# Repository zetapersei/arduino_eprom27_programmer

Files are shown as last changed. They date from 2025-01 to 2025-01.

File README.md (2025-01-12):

# Programmer for EPROM 27 series (16-512) based on Arduino

*You can download the stable version on the "Releases" tab. It guarantees a working version of the source code, compiled by the GUI for Windows and a sketch for arduino.*

Compatible Chips List (not all chips are tested):

 * 27C16 (connects from 3 to 26 leg DIP28 socket)
 * 27C32 (connects from 3 to 26 leg DIP28 socket)
 * 27C64
 * 27C128
 * 27C256
 * 27C512

Before write, check programming voltage in datasheet! 

# Schematic

Based on the project: https://github.com/bouletmarc/BMBurner

Schematic

PCB divorced using autotracer. Not yet tested, but the prototype is working properly.

*Resistors R1 and R2 are indicated in the Arduino firmware. By default, the values are 10 kOhm and 1.5 kOhm.*

# Software

Software for PC written by Qt5.

Functions:

 * Read chip
 * Write chip
 * Verify and check for write (no bits to be set to 1)
 * Programming voltage control (for AVR in TQFP case)

GUI on Windows 10

Requared Windows 7 or later.

GUI on Ubuntu Mate

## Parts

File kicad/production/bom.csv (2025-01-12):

Designator | Footprint | Quantity | Value | LCSC Part #
D1, D2, D3, D4, D5 | D_DO-35_SOD27_P7.62mm_Horizontal | 5 | 1N4148
IC1 | DIP-16_W7.62mm_LongPads | 1 | 74HC595D
IC2 | DIP-16_W7.62mm_LongPads | 1 | 74595D
J2 | PinHeader_1x02_P2.54mm_Vertical | 1 | Conn_01x02
Q1, Q2, Q3, Q4, Q5 | TO-92_Inline | 5 | BC557
Q6, Q7, Q8 | TO-92_Inline | 3 | BC547
R1, R2 | R_Axial_DIN0207_L6.3mm_D2.5mm_P10.16mm_Horizontal | 2 | R
R10, R11, R3, R4, R5, R6, R7, R8, R9 | R_Axial_DIN0207_L6.3mm_D2.5mm_P10.16mm_Horizontal | 9 | 22K
R12, R13, R14, R15 | R_Axial_DIN0207_L6.3mm_D2.5mm_P10.16mm_Horizontal | 4 | 4.7K
R16, R17 | R_Axial_DIN0207_L6.3mm_D2.5mm_P10.16mm_Horizontal | 2 | 300
U1 | Arduino_Nano_Socket | 1 | NANO
U2 | MT3608 | 1 | DC-DC-STEP-UP-MT3608
U3 | DIP_Socket-28_W11.9_W12.7_W15.24_W17.78_W18.5_3M_228-1277-00-0602J | 1 | 27C512

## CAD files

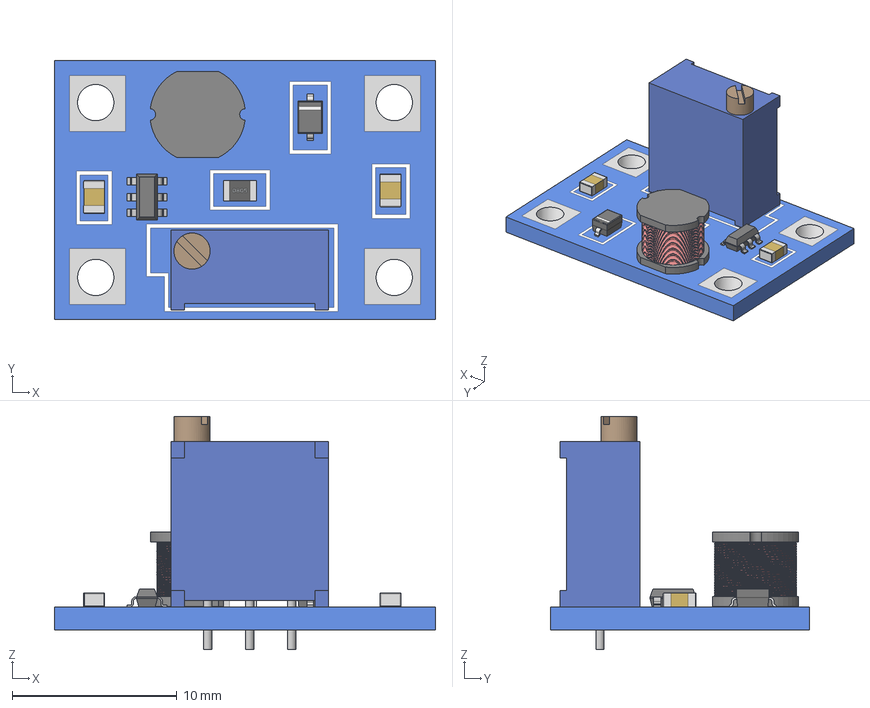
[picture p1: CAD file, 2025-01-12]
kicad/3D/Voltage Boost -Compact.stp
23.1 x 15.7 x 14.2 mm
MT3608-Module - Compact
Trimpot_3296W
0805 Capacitor x 2
CD54
sot-23-6-2
0805 Resistor
Diode (SOD-323)

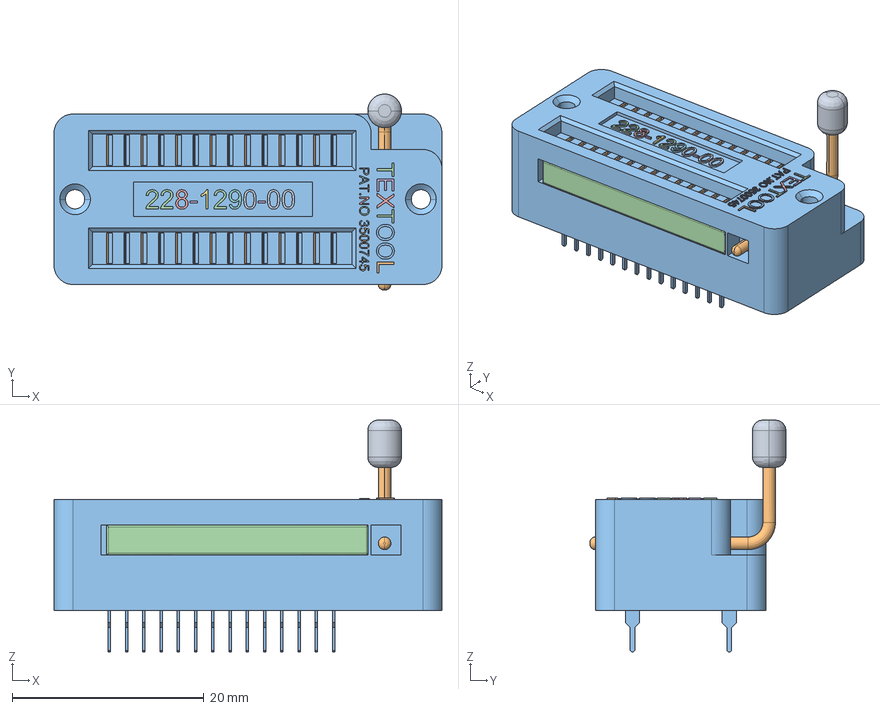
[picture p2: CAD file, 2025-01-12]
kicad/3D/textool.stp
40.5 x 20.5 x 24.2 mm

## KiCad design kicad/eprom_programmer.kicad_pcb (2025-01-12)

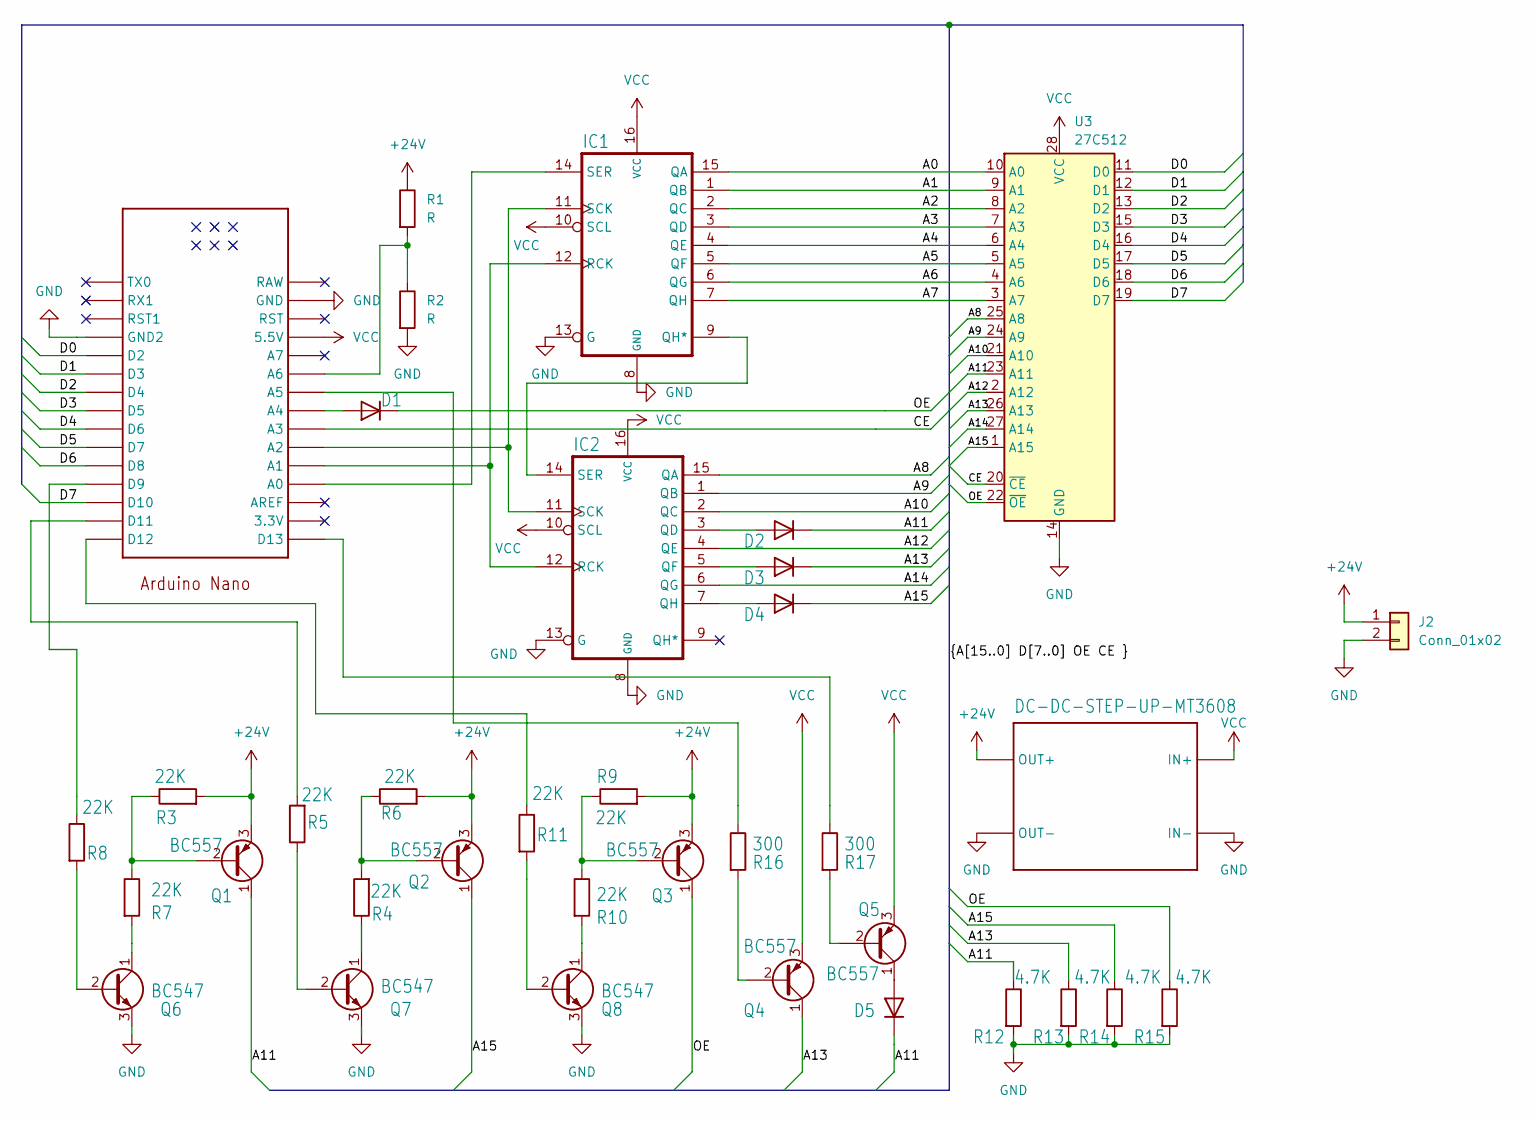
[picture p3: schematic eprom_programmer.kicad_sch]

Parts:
D1, D2, D3, D4, D5: 1N4148; D_DO-35_SOD27_P7.62mm_Horizontal
IC1: 74HC595D; DIP-16_W7.62mm_LongPads
IC2: 74595D; DIP-16_W7.62mm_LongPads
J2: Conn_01x02; PinHeader_1x02_P2.54mm_Vertical
Q1, Q2, Q3, Q4, Q5: BC557; TO-92_Inline
Q6, Q7, Q8: BC547; TO-92_Inline
R1, R2: R; R_Axial_DIN0207_L6.3mm_D2.5mm_P10.16mm_Horizontal
R3, R4, R5, R6, R7, R8, R9, R10, R11: 22K; R_Axial_DIN0207_L6.3mm_D2.5mm_P10.16mm_Horizontal
R12, R13, R14, R15: 4.7K; R_Axial_DIN0207_L6.3mm_D2.5mm_P10.16mm_Horizontal
R16, R17: 300; R_Axial_DIN0207_L6.3mm_D2.5mm_P10.16mm_Horizontal
U1: NANO
U2: DC-DC-STEP-UP-MT3608; MT3608
U3: 27C512; DIP_Socket-28_W11.9_W12.7_W15.24_W17.78_W18.5_3M_228-1277-0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

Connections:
+24V: J2.1, Q1.3 (E), Q2.3 (E), Q3.3 (E), R1.1, R3.2, R6.2, R9.2, U2.OUT+
/A0: IC1.15 (QA), U3.10 (A0)
/A1: IC1.1 (QB), U3.9 (A1)
/A2: IC1.2 (QC), U3.8 (A2)
/A3: IC1.3 (QD), U3.7 (A3)
/A4: IC1.4 (QE), U3.6 (A4)
/A5: IC1.5 (QF), U3.5 (A5)
/A6: IC1.6 (QG), U3.4 (A6)
/A7: IC1.7 (QH), U3.3 (A7)
/A8: IC2.15 (QA), U3.25 (A8)
/A9: IC2.1 (QB), U3.24 (A9)
/A10: IC2.2 (QC), U3.21 (A10)
/A11: D2.1 (K), D5.1 (K), Q1.1 (C), R12.1, U3.23 (A11)
/A12: IC2.4 (QE), U3.2 (A12)
/A13: D3.1 (K), Q4.1 (C), R13.1, U3.26 (A13)
/A14: IC2.6 (QG), U3.27 (A14)
/A15: D4.1 (K), Q2.1 (C), R14.1, U3.1 (A15)
/CE: U1.A3, U3.20 (~CE)
/D0: U1.D2, U3.11 (D0)
/D1: U1.D3, U3.12 (D1)
/D2: U1.D4, U3.13 (D2)
/D3: U1.D5, U3.15 (D3)
/D4: U1.D6, U3.16 (D4)
/D5: U1.D7, U3.17 (D5)
/D6: U1.D8, U3.18 (D6)
/D7: U1.D10, U3.19 (D7)
/OE: D1.1 (K), Q3.1 (C), R15.1, U3.22 (~OE)
GND: IC1.8 (GND), IC1.13 (G), IC2.8 (GND), IC2.13 (G), J2.2, Q6.3 (E), Q7.3 (E), Q8.3 (E), R2.2, R12.2, R13.2, R14.2, R15.2, U1.GND, U1.GND1 (GND2), U2.IN-, U2.OUT-, U3.14 (GND)
unnamed: D1.2 (A), U1.A4
unnamed: D2.2 (A), IC2.3 (QD)
unnamed: D3.2 (A), IC2.5 (QF)
unnamed: D4.2 (A), IC2.7 (QH)
unnamed: D5.2 (A), Q5.1 (C)
unnamed: IC1.9 (QH*), IC2.14 (SER)
unnamed: IC1.12 (RCK), IC2.12 (RCK), U1.A1
unnamed: IC1.11 (SCK), IC2.11 (SCK), U1.A2
unnamed: IC1.14 (SER), U1.A0
unnamed: Q1.2 (B), R3.1, R7.1
unnamed: Q2.2 (B), R4.2, R6.1
unnamed: Q3.2 (B), R9.1, R10.1
unnamed: Q4.2 (B), R16.2
unnamed: Q5.2 (B), R17.2
unnamed: Q6.2 (B), R8.2
unnamed: Q6.1 (C), R7.2
unnamed: Q7.2 (B), R5.1
unnamed: Q7.1 (C), R4.1
unnamed: Q8.2 (B), R11.2
unnamed: Q8.1 (C), R10.2
unnamed: R1.2, R2.1, U1.A6
unnamed: R5.2, U1.D11
unnamed: R8.1, U1.D9
unnamed: R11.1, U1.D12
unnamed: R16.1, U1.A5
unnamed: R17.1, U1.D13
VCC: IC1.10 (SCL), IC1.16 (VCC), IC2.10 (SCL), IC2.16 (VCC), Q4.3 (E), Q5.3 (E), U1.5V (5.5V), U2.IN+, U3.28 (VCC)

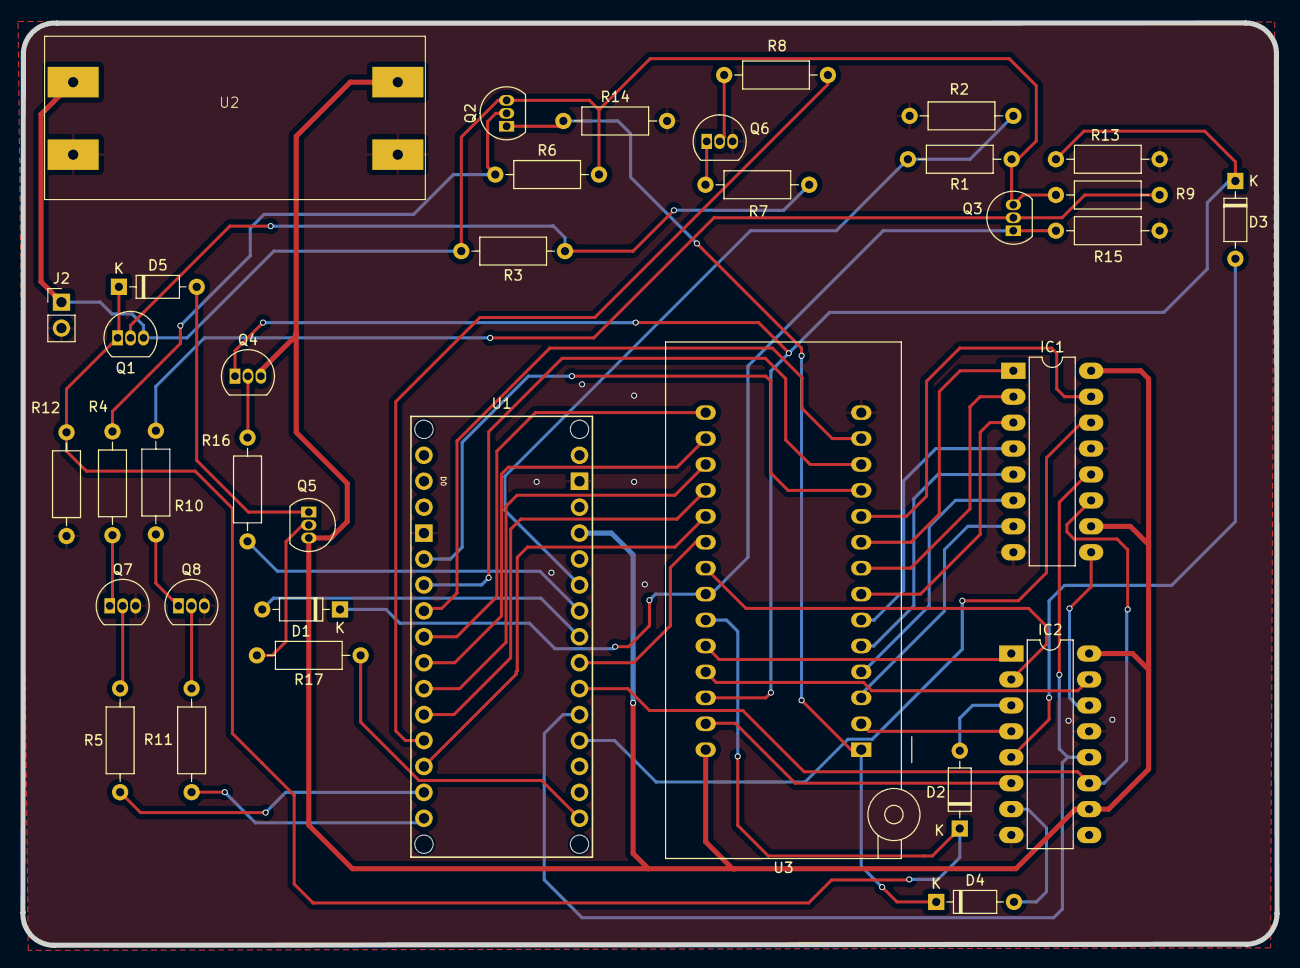
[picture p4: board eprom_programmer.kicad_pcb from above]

Board: 2 copper layers, 122.8 x 90.3 mm, 36 parts (0 on the bottom side), 55 nets.

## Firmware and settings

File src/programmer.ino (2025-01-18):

#include <Arduino.h>

#define TRUE 1
#define FALSE 0

/* 74HC595 control (address lines) */
#define shiftLatchPin A1
#define shiftClockPin A2
#define shiftDataPin A0
#define addressPinA10 13

/* Data pins */
#define dataB0 2
#define dataB1 3
#define dataB2 4
#define dataB3 5
#define dataB4 6
#define dataB5 7
#define dataB6 8
#define dataB7 10

/* Chip control */
#define chipEnable A3
#define outputEnable A4
#define powerEnable A5 // For 27C16 and 27C32
#define readVoltageEnable 13 // For 27C16
#define programVoltageEnableC16 9 // For 27C16
#define programVoltageEnableC32 12 // For 27C32 and 27C512
#define programVoltageEnableOther 11 // For other

/* Voltage control (for programming chips) */
#define voltageControl A6
#define rTop 10000.0
#define rBottom 1500.0

//#define MESSAGES

typedef enum chipType {
  NONE = 0,
  C16 = 1,
  C32 = 2,
  C64 = 3,
  C128 = 4,
  C256 = 5,
  C512 = 6
} Chip;

typedef enum mode {
  WAIT,
  READ,
  WRITE,
  VOLTAGE
} Modes;


void write_mode (void);
void read_mode (void);
void set_address (uint16_t address);
uint8_t get_data (void);
void set_data (uint8_t data);
uint8_t read_byte (uint16_t address);
void write_byte (uint16_t address, uint8_t data);
float get_voltage (void);
void program_voltage_set (bool state);
uint16_t gen_address (uint16_t address);
void select_chip (chipType new_chip);

chipType chip = NONE;
Modes mode = WAIT;
uint8_t log_enable = FALSE;
uint16_t start_address = 0x0000;
uint16_t end_address = 0x0000;
#define BUF_LEN 16
uint8_t buf[BUF_LEN];

void message(const char* mes){
	if (log_enable)
		Serial.println(mes);
}

void setup() {
  // 74HC595 (*2)
  pinMode(shiftLatchPin, OUTPUT);
  pinMode(shiftClockPin, OUTPUT);
  pinMode(shiftDataPin, OUTPUT);
  pinMode(addressPinA10, OUTPUT);

  // Chip control
  pinMode(chipEnable, OUTPUT);
  pinMode(outputEnable, OUTPUT);
  pinMode(powerEnable, OUTPUT);
  pinMode(readVoltageEnable, OUTPUT);
  pinMode(programVoltageEnableC16, OUTPUT);
  pinMode(programVoltageEnableC32, OUTPUT);
  pinMode(programVoltageEnableOther, OUTPUT);
  digitalWrite(outputEnable, HIGH);
  digitalWrite(powerEnable, HIGH);
  digitalWrite(readVoltageEnable, HIGH);
  digitalWrite(programVoltageEnableC16, LOW);
  digitalWrite(programVoltageEnableC32, LOW);
  digitalWrite(programVoltageEnableOther, LOW);
  digitalWrite(chipEnable, LOW);

  // Data pins
  read_mode();

  Serial.begin(115200);
  Serial.println("Arduino 27 Series programmer");
}

void loop() {
  switch (mode) {
    case READ:
      if (chip == NONE) {
        mode = WAIT;
        break;
      }
      message("Read mode.");
      read_mode();
      if (chip == C16) digitalWrite(readVoltageEnable, LOW);
      digitalWrite(chipEnable, LOW);
      digitalWrite(outputEnable, LOW);
      for (uint16_t i = start_address; i <= end_address; i++) {
        uint8_t data = read_byte(i);
        Serial.write(&data, sizeof(data));
        if (i == end_address) break; // Защита от переполнения uint16
      }
      digitalWrite(outputEnable, HIGH);
      digitalWrite(chipEnable, HIGH);
      if (chip == C16) digitalWrite(readVoltageEnable, HIGH);
      mode = WAIT;
      break;
    case WRITE:
      if (chip == NONE) {
        mode = WAIT;
        break;
      }
      message("Write mode");
      for (int i = start_address; i <= end_address; i++) {
        Serial.println(i, HEX);
        write_byte(i, 0x89);
        }
      for (uint16_t i = start_address; i <= end_address; i += BUF_LEN) {
        Serial.print("Write block ");
        Serial.println(i);
        uint8_t count = Serial.readBytes((char*)buf, BUF_LEN);
        if (count != BUF_LEN) {
          Serial.print("Error on block");
          Serial.println(i);
          Serial.print("Received ");
          Serial.println(count);
          break;
        }
        for (uint16_t j = 0; j < BUF_LEN; j++) {
					// Write byte
					write_mode();
					program_voltage_set(true);
          write_byte((i + j), buf[j]);
					program_voltage_set(false);

					// Verify byte
					read_mode();
					if (chip == C16) digitalWrite(readVoltageEnable, LOW);
					digitalWrite(chipEnable, LOW);
					digitalWrite(outputEnable, LOW);
					uint8_t verify = get_data();
					digitalWrite(outputEnable, HIGH);
					digitalWrite(chipEnable, HIGH);
					if (chip == C16) digitalWrite(readVoltageEnable, HIGH);
					if (buf[j] != verify){
						Serial.print("Error on address ");
						Serial.println(i + j);
						mode = WAIT;
					}
        }
        Serial.print("Complete block ");
        Serial.println(i);
        if (i == end_address) break;
      }
      message("Write success.");
      mode = WAIT;
      break;
    case VOLTAGE:
      Serial.print("Programming voltage: ");
      Serial.println(get_voltage(), 1);
      mode = WAIT;
      break;
    default:
      if (chip == NONE) message("Chip not selected!");
      message("Wait commands...");
      while (Serial.available()) Serial.read();
      do {} while (Serial.available() == 0);
      char incomingByte = Serial.read();
      while (Serial.available()) Serial.read();
      switch (incomingByte) {
        case 'r': mode = READ; break;
        case 'w': mode = WRITE; break;
        case 'v': mode = VOLTAGE; break;
        case 'a': select_chip(C16); break;
        case 'b': select_chip(C32); break;
        case 'c': select_chip(C64); break;
        case 'd': select_chip(C128); break;
        case 'e': select_chip(C256); break;
        case 'f': select_chip(C512); break;
      }
  }
}

void select_chip (chipType new_chip) {
  digitalWrite(powerEnable, HIGH);
  switch (new_chip) {
    case C16:
      digitalWrite(powerEnable, LOW);
      chip = new_chip;
      end_address = 0x07ff;
			message("Select 27C16 chip.");
      break;
    case C32:
      digitalWrite(powerEnable, LOW);
      chip = new_chip;
      end_address = 0x0fff;
			message("Select 27C32 chip.");
      break;
    case C64:
      chip = new_chip;
      end_address = 0x1fff;
			message("Select 27C64 chip.");
      break;
    case C128:
      chip = new_chip;
      end_address = 0x3fff;
			message("Select 27C128 chip.");
      break;
    case C256:
      chip = new_chip;
      end_address = 0x7fff;
			message("Select 27C256 chip.");
      break;
    case C512:
      chip = C512;
      end_address = 0xffff;
			message("Select 27C512 chip.");
      break;
    default:
      chip = NONE;
      end_address = 0x0000;
			message("Chip not selected!");
  }
}


void program_voltage_set (bool state) {
  switch (chip) {
    case C16:
      digitalWrite(programVoltageEnableC16, state);
      break;
    case C32:
    case C512:
      digitalWrite(programVoltageEnableC32, state);
      break;
    case C64:
    case C128:
    case C256:
    default:
      digitalWrite(programVoltageEnableOther, state);
  }
}

void write_mode (void) {
  pinMode(dataB0, OUTPUT);
  pinMode(dataB1, OUTPUT);
  pinMode(dataB2, OUTPUT);
  pinMode(dataB3, OUTPUT);
  pinMode(dataB4, OUTPUT);
  pinMode(dataB5, OUTPUT);
  pinMode(dataB6, OUTPUT);
  pinMode(dataB7, OUTPUT);
}

void read_mode (void) {
  pinMode(dataB0, INPUT_PULLUP);
  pinMode(dataB1, INPUT_PULLUP);
  pinMode(dataB2, INPUT_PULLUP);
  pinMode(dataB3, INPUT_PULLUP);
  pinMode(dataB4, INPUT_PULLUP);
  pinMode(dataB5, INPUT_PULLUP);
  pinMode(dataB6, INPUT_PULLUP);
  pinMode(dataB7, INPUT_PULLUP);
}

uint16_t gen_address (uint16_t address) {
  byte high = highByte(address);
  byte low = lowByte(address);
  switch (chip) {
    case C16:
      break;
      if (mode == READ) {
        high |= 1 << 3; // A11 (C32+) is Vpp for C16 (5v for read)
      }
      break;
    case C64:
    case C128:
      if (mode == READ) {
        high |= 1 << 6; // A14 (C256 and C512) is ~PGM for C64 and C128
      }
      break;
    case C32:
    case C256:
    case C512:
    default:
      break;
  }
  return (high << 8) | low;
}

void set_address (uint16_t address) {
  address = gen_address(address);
  digitalWrite(shiftLatchPin, LOW);
  byte registerTwo = highByte(address);
  byte registerOne = lowByte(address);
  shiftOut(shiftDataPin, shiftClockPin, MSBFIRST, registerTwo);
  shiftOut(shiftDataPin, shiftClockPin, MSBFIRST, registerOne);
  digitalWrite(shiftLatchPin, HIGH);
}

uint8_t get_data (void) {
  uint8_t data = 0;
  data |= digitalRead(dataB0) << 0;
  data |= digitalRead(dataB1) << 1;
  data |= digitalRead(dataB2) << 2;
  data |= digitalRead(dataB3) << 3;
  data |= digitalRead(dataB4) << 4;
  data |= digitalRead(dataB5) << 5;
  data |= digitalRead(dataB6) << 6;
  data |= digitalRead(dataB7) << 7;
  return data;
}

void set_data (uint8_t data) {
  digitalWrite(dataB0, (data & (1 << 0)));
  digitalWrite(dataB1, (data & (1 << 1)));
  digitalWrite(dataB2, (data & (1 << 2)));
  digitalWrite(dataB3, (data & (1 << 3)));
  digitalWrite(dataB4, (data & (1 << 4)));
  digitalWrite(dataB5, (data & (1 << 5)));
  digitalWrite(dataB6, (data & (1 << 6)));
  digitalWrite(dataB7, (data & (1 << 7)));
}

uint8_t read_byte (uint16_t address) {
  set_address(address);
  return get_data();
}

void write_byte (uint16_t address, uint8_t data) {
  set_address(address);
  set_data(data);
  switch (chip) {
    case C16:
      digitalWrite(chipEnable, HIGH);
      delay(15);
      digitalWrite(chipEnable, LOW);
      break;
    case C32:
    case C64:
    case C128:
    case C256:
    case C512:
    default:
      digitalWrite(chipEnable, LOW);
      delayMicroseconds(110);
      digitalWrite(chipEnable, HIGH);
      break;
  }
}

float get_voltage (void) {
  float vADC = (analogRead(voltageControl) / 1024.) * 5.;
  float current = vADC / rBottom;
  return (current * (rTop + rBottom));
}

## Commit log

2025-01-12 modified: .gitignore new file: .vscode/extensions.json deleted: README.md deleted: eagle/untitled.brd deleted: eagle/untitled.sch deleted: gui/arduino.cpp deleted: gui/arduino.h deleted: gui/gui.pro 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
    [Voltage Boost -Compact.stp, bom.csv, designators.csv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]
2025-01-12 new file: gui/arduino.cpp new file: gui/arduino.h new file: gui/gui.pro new file: gui/icon.ico new file: gui/icon.rc new file: gui/main.cpp new file: gui/mainwindow.cpp new file: gui/mainwindow.h new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
2025-01-18 # Please enter the commit message for your change # with ' ' will be ignored, and an empty message aborts the commit. # On branch master # Your branch is up to date with 'origin/master'. # Changes to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
